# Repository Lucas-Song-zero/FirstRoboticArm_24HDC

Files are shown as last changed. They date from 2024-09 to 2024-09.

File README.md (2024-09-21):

# 总体介绍
本项目为清华大学电子工程系第27届硬件设计大赛一等奖作品——First机械手 (First Robotic Arm)

**README文档还在更新中**

#### 亮点：
1. 线驱动机械手
2. 大扭矩舵机（尽可能好的控制机械臂）
3. 设计集成度较高的压敏电阻测量模块(PCB)
4. 设计拓展版(PCB)实现更集成的功能、更美观和更高的稳定性
5. 10通道测量,更精确地测量各个关节角度
6. 使用K210实现手势识别,输出数据控制机械手
7. 使用电位计和MPU6050分别测量手肘旋转角度和小臂自转角度

#### 不足：
1. 机械手手指扭矩力道不足,精度不够高
2. 压敏电阻转换非线性,目前只能进行0-1输出
3. ESP32使用WIFI时会导致板载ADC2通道引脚失效,可以使用IO拓展增加ADC引脚
4. 设计的拓展板尺寸稍有不对,宽度大概多了1mm左右
5. K210和ESP8266的通讯很棘手,还没有完成

#### 未来可以改进的方向：
1. 显然换成电机控制会让机械臂效果好很多
2. 10自由度--5自由度机械手已经可以完成大部分日常工作
3. 压敏电阻使用反比例函数模型进行数据拟合，获得更好的效果  (大概x)

# 本Proj文件树结构:
**截止2024/9/21**
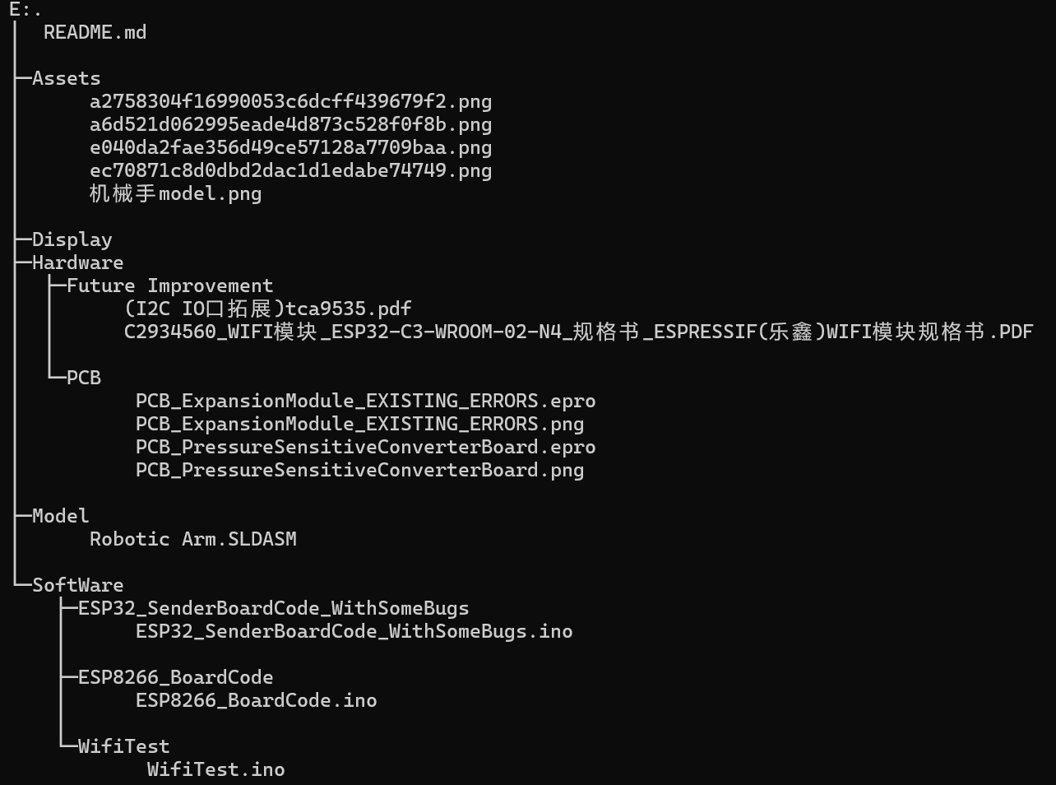
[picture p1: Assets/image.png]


# 本项目详细介绍
### 1. 机械结构+舵机安装
由whj同学进行多版机械手+机械臂结构设计以及舵机的安装。

整个过程很复杂，尤其是舵机的布线 (我们最终选择风筝线作为固定线，兼具一定的弹性和大拉力) 以及3D打印的设计需要对尺寸很强的把握。

我们总共打印了5~6版结构，最终实现了比较好的整体效果

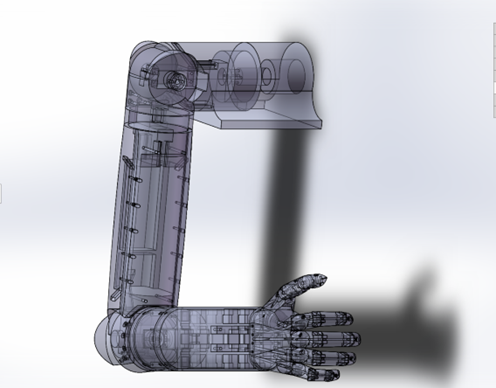
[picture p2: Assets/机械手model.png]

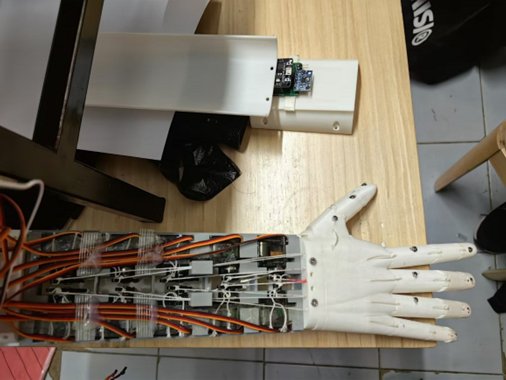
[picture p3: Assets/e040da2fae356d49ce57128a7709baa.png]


### 2. CNN
由ykp同学进行CNN架构搭建和本地跑一个轻量化CV模型，实现了基本的手势分类，准确率达到90%以上(至少显示的如此，具体使用中因为摄像范围、帧数限制等原因会降低其识别准确率)。

将这个轻量化模型部署到K210上(这里K210自带的Flash已经不足以支持这些参数的模型，所以使用了SD卡扩容)

PS: SD卡也是一个很容易出现Bug的地方（悲）
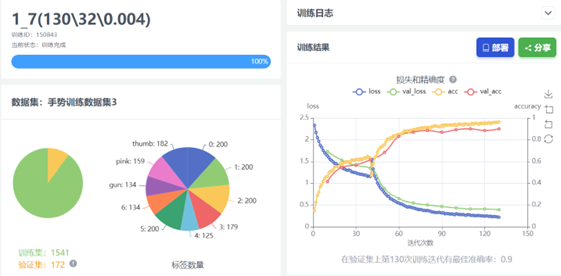
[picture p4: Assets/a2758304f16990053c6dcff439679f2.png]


### 3. 传感模块（by Lucas Song）
我创新性的使用了压敏电阻检测手指关节弯曲程度，原理很简单：将压敏电阻紧贴在手指关节处，当手指关节弯曲时，会对手指关节处的压敏电阻产生一个压力，改变其电阻阻值，从而实现从弯曲角度到电阻阻值的转化。

当然，最初方案不是这样，最初我使用的是应变片，这个不仅贵（一小片要十几块钱,我当时斥巨资买了120元的,最后一个没用上x）,变化范围极小（350±2Ω）,而且非常脆弱（根部不小心就断了）。这个"spider"方案耗费了我们1~2周时间，期间sxz同学一直在为其绘制PCB版，但是最终因为GND打孔问题导致PCB失败，整体方案替换为现在的压敏电阻。

压敏电阻变化范围非常大：KΩ~MΩ量级变化，可以说非常适合本次任务。
唯一美中不足的是使用压敏电阻可能需要数据拟合才能得到较为正确的实时角度值，但是因为时间原因以及技术复杂度，我们最终选择的是进行范围分割，只输出0、90、-1（表示无效数据）三个值只做最简单的控制。

下图是我最开始给应变片方案设计的PCB采集电路(还花了我不少钱去买运放 (生气) )

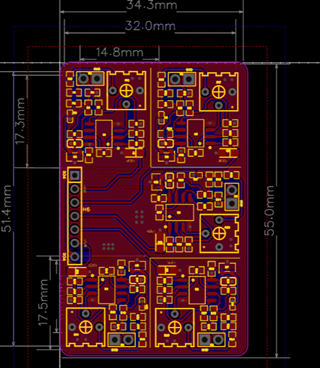
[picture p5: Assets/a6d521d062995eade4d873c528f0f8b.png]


更改方案2之后我们先是使用淘宝上买的器件做了一个小Demo(下图) ，并且用它参与了初试

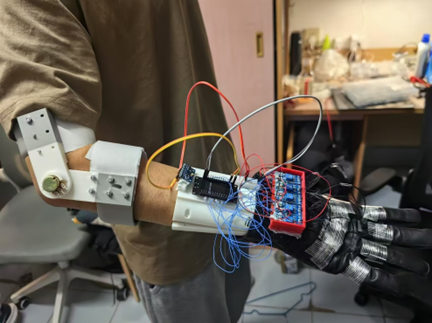
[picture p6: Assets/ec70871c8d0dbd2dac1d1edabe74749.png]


后面sxz同学的主要工作就是优化传感部分的结构：打了一个新传感模块+一个拓展板。以及优化整体的数据获取+通信模块。

**anecdote**:在决赛的前一天晚上才焊好所有板子并开始编写手指--机械手部分的控制代码，最终耗费一上午也是勉强赶上DDL了（）。这个故事告诉我们做事不要拖，不然会很破防（确信）

以及我要狠狠吐槽ESP32打开WiFi之后ADC2通道的所有引脚模拟量测量失效，1天半基本都是在怼这个问题，我开始甚至不知道，一直以为是自己的拓展板设计错了（悲）。

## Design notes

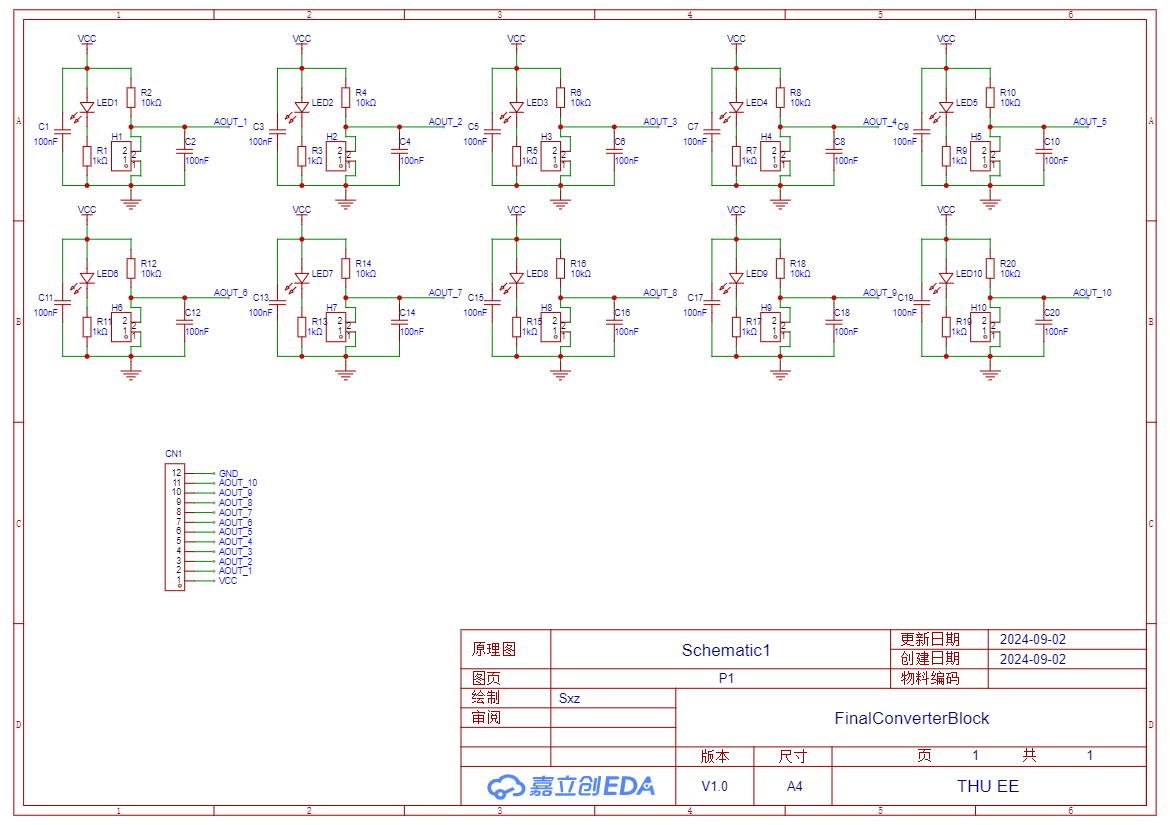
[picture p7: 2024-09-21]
Hardware/PCB/PCB_PressureSensitiveConverterBoard.png

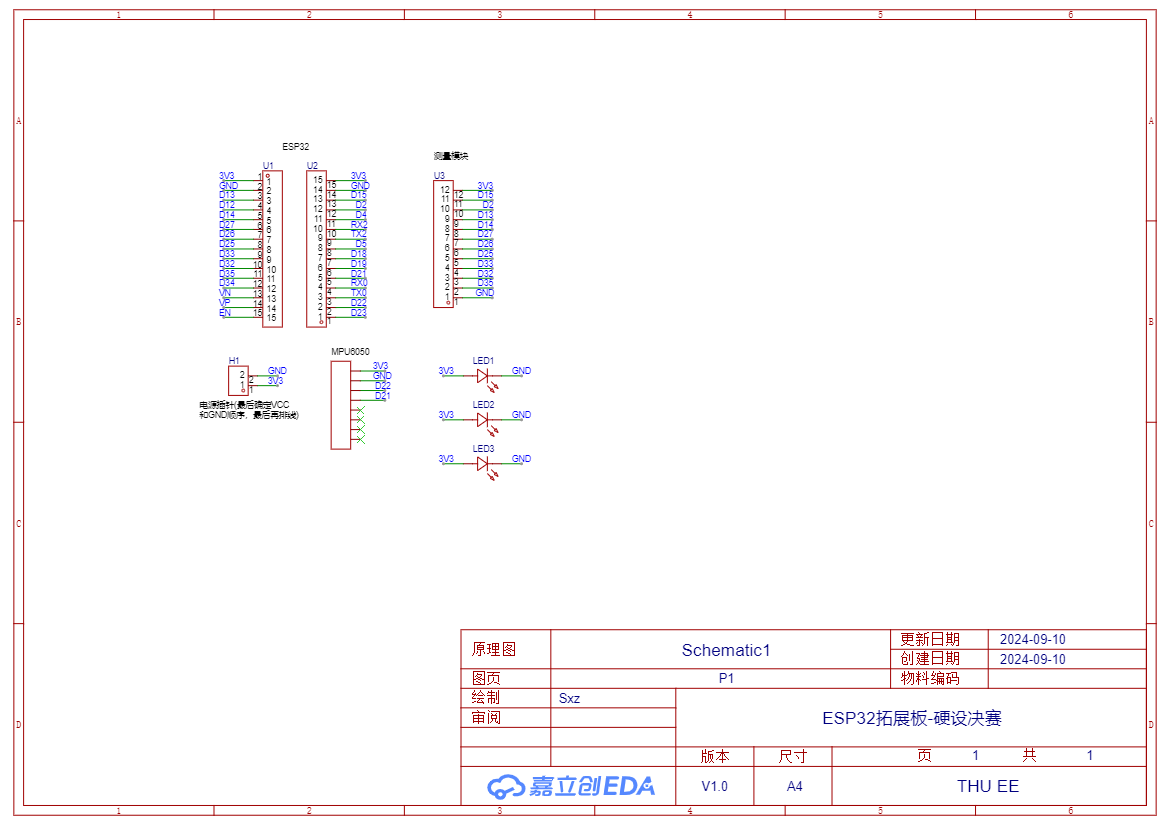
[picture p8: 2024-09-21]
Hardware/PCB/PCB_ExpansionModule_EXISTING_ERRORS.png

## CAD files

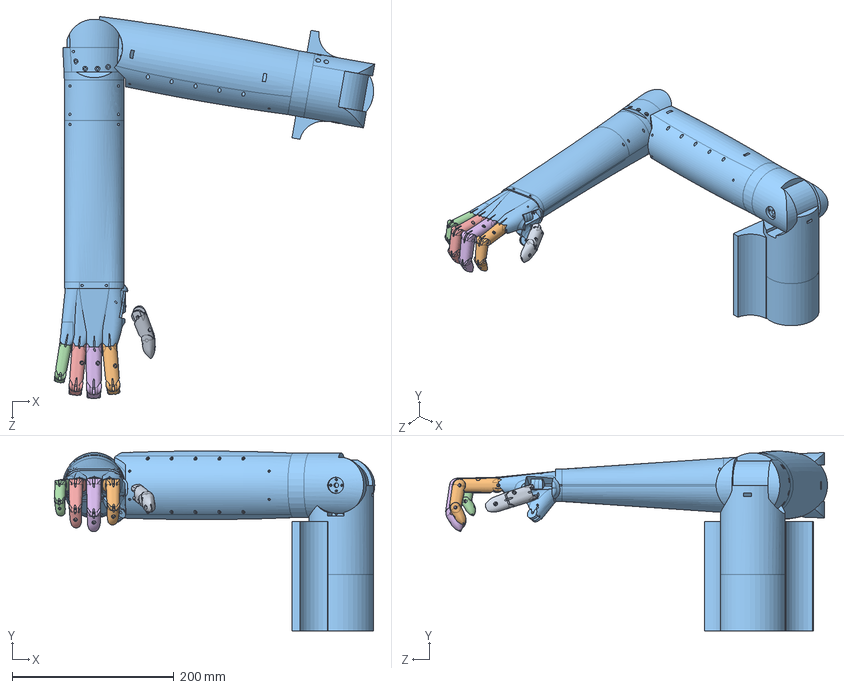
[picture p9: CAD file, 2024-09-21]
Model/Robotic Arm.SLDASM
396.2 x 222.3 x 472.1 mm
拇指1
食指2
手掌2
小指2
无名指2
中指2

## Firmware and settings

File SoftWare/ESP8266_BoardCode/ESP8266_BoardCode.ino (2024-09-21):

#include <ESP8266WiFi.h>
#include <espnow.h>
#include <Wire.h>
#include <Adafruit_PWMServoDriver.h>
Adafruit_PWMServoDriver pwm = Adafruit_PWMServoDriver(0x40);
Adafruit_PWMServoDriver pwm1 = Adafruit_PWMServoDriver(0x41);
#define Deg_0 102
#define Deg_10 114
#define Deg_20 134
#define Deg_30 155
#define Deg_40 176
#define Deg_45 187
#define Deg_50 197
#define Deg_60 218
#define Deg_70 239
#define Deg_75 249
#define Deg_80 259
#define Deg_90 280
#define Deg_100 301
#define Deg_110 321
#define Deg_120 342
#define Deg_130 363
#define Deg_140 383
#define Deg_150 398
#define Deg_160 425
#define Deg_170 446
#define Deg_180 510 
#define INT 4

static int mode = 1; // 0--跟随模式; 1--自动演示模式; 2--K210连接模式
static String comdata = ""; // 接受从K210收集到的数据
uint32_t timeCur = 0;
int fingerangles[3];
bool recData = false;

typedef struct FromESP32
{
  int FingerAngles[3]; // 10个手指关节对应的角度，从大拇指根开始0,大拇指第二个关节1,食指根2,依次到小拇指第二个关节9
} FromESP32;
FromESP32 from32;

typedef struct From8266
{
  int id;
  int shape;
} From8266;
From8266 from8266;

void OnDataRecv(uint8_t* mac_addr, uint8_t* incomingData, uint8_t len)
{
  memcpy(&from32, incomingData, sizeof(from32));
  Serial.printf("1:%d  2:%d  3:%d\n",from32.FingerAngles[0],from32.FingerAngles[1],from32.FingerAngles[2]);
  recData = true;
}

void OnDataRecv2(uint8_t* mac_addr, uint8_t* incomingData, uint8_t len)
{
  memcpy(&from8266, incomingData, sizeof(from8266));
  Serial.printf("Recv: %d\n",from8266.shape);
}

void setup() {
  // put your setup code here, to run once:
  Serial.begin(9600);
  WiFi.mode(WIFI_STA);

  // set the Interrupt Pin
  pinMode(INT, INPUT_PULLUP);
  attachInterrupt(INT, isr, FALLING); // 配置INT(4号引脚)在按下按钮(下降沿)将MODE切换

  // Init ESP-NOW
  if(esp_now_init()!= 0)
  {
    Serial.println("Error Init ESP-NOW");
    return;
  }
  // After ESP-NOW Init is Done, register for recv CB to get recv Packer Info
  // esp_now_register_recv_cb(esp_now_recv_cb_t(OnDataRecv));

  // only for test
  esp_now_set_self_role(ESP_NOW_ROLE_SLAVE);
  esp_now_register_recv_cb(OnDataRecv);
  Serial.begin(9600);
  pwm.begin();
  pwm.setPWMFreq(50);// 50HZ更新频率，相当于20ms的周期
  pwm1.begin();
  pwm1.setPWMFreq(50);// 50HZ更新频率，相当于20ms的周期
  delay(100);
}

void five()//完全张开//五
{pwm.setPWM(1, 0, Deg_50);//拇指根
pwm.setPWM(6, 0, Deg_140);//拇指中
pwm.setPWM(8, 0, Deg_130);//拇指前
pwm.setPWM(2, 0, Deg_150);//食指根
pwm.setPWM(4, 0, Deg_170);//食指中
pwm.setPWM(3, 0, Deg_10);//中指中
pwm.setPWM(0, 0, Deg_120);//中指根
pwm.setPWM(7, 0, Deg_40);//无名中
pwm.setPWM(5, 0, Deg_50);//无名根
pwm.setPWM(9, 0, Deg_0);//小指
}

void one()//一
{pwm.setPWM(1, 0, Deg_180);//拇指根
pwm.setPWM(6, 0, Deg_100);//拇指中
pwm.setPWM(8, 0, Deg_100);//拇指前
pwm.setPWM(2, 0, Deg_150);//食指根
pwm.setPWM(4, 0, Deg_170);//食指中
pwm.setPWM(3, 0, Deg_120);//中指中
pwm.setPWM(0, 0, Deg_30);//中指根
pwm.setPWM(7, 0, Deg_160);//无名中
pwm.setPWM(5, 0, Deg_130);//无名根
pwm.setPWM(9, 0, Deg_180);//小指
}

void two()//二
{pwm.setPWM(1, 0, Deg_180);//拇指根
pwm.setPWM(6, 0, Deg_100);//拇指中
pwm.setPWM(8, 0, Deg_100);//拇指前
pwm.setPWM(2, 0, Deg_150);//食指根
pwm.setPWM(4, 0, Deg_170);//食指中
pwm.setPWM(3, 0, Deg_10);//中指中
pwm.setPWM(0, 0, Deg_120);//中指根
pwm.setPWM(7, 0, Deg_160);//无名中
pwm.setPWM(5, 0, Deg_130);//无名根
pwm.setPWM(9, 0, Deg_180);//小指
}

void three()//三
{pwm.setPWM(1, 0, Deg_180);//拇指根
pwm.setPWM(6, 0, Deg_100);//拇指中
pwm.setPWM(8, 0, Deg_100);//拇指前
pwm.setPWM(2, 0, Deg_150);//食指根
pwm.setPWM(4, 0, Deg_170);//食指中
pwm.setPWM(3, 0, Deg_10);//中指中
pwm.setPWM(0, 0, Deg_120);//中指根
pwm.setPWM(7, 0, Deg_40);//无名中
pwm.setPWM(5, 0, Deg_50);//无名根
pwm.setPWM(9, 0, Deg_180);//小指
}
void four()//四
{pwm.setPWM(1, 0, Deg_180);//拇指根
pwm.setPWM(6, 0, Deg_100);//拇指中
pwm.setPWM(8, 0, Deg_100);//拇指前
pwm.setPWM(2, 0, Deg_150);//食指根
pwm.setPWM(4, 0, Deg_170);//食指中
pwm.setPWM(3, 0, Deg_10);//中指中
pwm.setPWM(0, 0, Deg_120);//中指根
pwm.setPWM(7, 0, Deg_40);//无名中
pwm.setPWM(5, 0, Deg_50);//无名根
pwm.setPWM(9, 0, Deg_0);//小指
}
void six()//六
{pwm.setPWM(1, 0, Deg_40);//拇指根
pwm.setPWM(6, 0, Deg_140);//拇指中
pwm.setPWM(8, 0, Deg_130);//拇指前
pwm.setPWM(2, 0, Deg_40);//食指根
pwm.setPWM(4, 0, Deg_70);//食指中
pwm.setPWM(3, 0, Deg_120);//中指中
pwm.setPWM(0, 0, Deg_30);//中指根
pwm.setPWM(7, 0, Deg_160);//无名中
pwm.setPWM(5, 0, Deg_130);//无名根
pwm.setPWM(9, 0, Deg_0);//小指
}
void thumb()//大拇指
{pwm.setPWM(1, 0, Deg_40);//拇指根
pwm.setPWM(6, 0, Deg_140);//拇指中
pwm.setPWM(8, 0, Deg_130);//拇指前
pwm.setPWM(2, 0, Deg_40);//食指根
pwm.setPWM(4, 0, Deg_70);//食指中
pwm.setPWM(3, 0, Deg_120);//中指中
pwm.setPWM(0, 0, Deg_30);//中指根
pwm.setPWM(7, 0, Deg_160);//无名中
pwm.setPWM(5, 0, Deg_130);//无名根
pwm.setPWM(9, 0, Deg_180);//小指
}
void fuck()//中指
{pwm.setPWM(1, 0, Deg_180);//拇指根
pwm.setPWM(6, 0, Deg_100);//拇指中
pwm.setPWM(8, 0, Deg_100);//拇指前
pwm.setPWM(2, 0, Deg_40);//食指根
pwm.setPWM(4, 0, Deg_70);//食指中
pwm.setPWM(3, 0, Deg_10);//中指中
pwm.setPWM(0, 0, Deg_120);//中指根
pwm.setPWM(7, 0, Deg_160);//无名中
pwm.setPWM(5, 0, Deg_130);//无名根
pwm.setPWM(9, 0, Deg_180);//小指
}

void SETPWM(Adafruit_PWMServoDriver pwm,int port,int initdeg,int finaldeg)//调整手臂关节
{int i=0;
if(initdeg>finaldeg)
{
  for(i=initdeg;i>finaldeg;i--)
  {
    pwm.setPWM(port,0,i);
    delay(5);
  }
}
else
{
  for(i=initdeg;i<finaldeg;i++)
  {
    pwm.setPWM(port,0,i);
    delay(5);
  }
}

}
IRAM_ATTR void isr()
{
  mode = (mode+1)%3;
}

void Follow()
{
  
  // from32是通过wifi获得的数据,内存的数据格式详情参见前面的定义
  int angles[3];
  if(recData) // 接受到数据,可以更新一次角度值
  {
    for(int i=0;i<3;++i)
    {
      angles[i]=from32.FingerAngles[i];
    }
    // 下面是角度控制
    if(angles[0]==90)
    {
      pwm.setPWM(2, 0, Deg_40);//食指根
      pwm.setPWM(4, 0, Deg_70);//食指中
    }
    else 
    {
      pwm.setPWM(2, 0, Deg_130);//食指根
      pwm.setPWM(4, 0, Deg_170);//食指中
    }
    if(angles[1]==90)
    {
      pwm.setPWM(0, 0, Deg_30);//中指根
      pwm.setPWM(3, 0, Deg_120);//中指中
    }
    else 
    {
      pwm.setPWM(0, 0, Deg_120);//中指根
      pwm.setPWM(3, 0, Deg_10);//中指中
    }
    if(angles[2]==90)
    {
      pwm.setPWM(1, 0, Deg_180);//拇指根
      pwm.setPWM(7, 0, Deg_160);//无名中
      pwm.setPWM(5, 0, Deg_130);//无名根
      pwm.setPWM(9, 0, Deg_180);//小指
    }
    else 
    {
      pwm.setPWM(1, 0, Deg_40);//拇指根
      pwm.setPWM(7, 0, Deg_40);//无名中
      pwm.setPWM(5, 0, Deg_50);//无名根
      pwm.setPWM(9, 0, Deg_0);//小指
    }

    // 下面是把recData设为false，等待下一次接受数据
    recData=false;
  }
  
 
  delay(1000);

}

void AutoDisplay()
{
  // 自动展示一些动作
  
  SETPWM(pwm1,1,Deg_70,Deg_10);
  pwm1.setPWM(8,0,Deg_0);
  delay(1500);
  // thumb();
  // delay(2000);
  one();
  delay(2000);
  two();
  delay(2000);
  three();
  delay(2000);
  four();
  delay(2000);
  five();
  delay(2000);
  six();
  delay(2000);
  five();
  SETPWM(pwm1,1,Deg_10,Deg_70);
  pwm1.setPWM(8,0,Deg_90);
  delay(2000);

}

void K210Link()
{
  // 和K210连接,接受信号
  while(1)
  {
    Serial.printf("Shape:%d",from8266.shape);

    switch(from8266.shape)
    {
      case 0:
      {
        fuck();
        break;
      }

      case 1:
      {
        five();
        delay(3000);
        one();
        break;
      }

      case 2:
      {
        two();
        break;
      }

      case 3:
      {
        four();
        delay(500);
        three();
        break;
      }

      case 4:
      {
        four();
        break;
      }

      case 5:
      {
        five();
        break;
      }

      case 6:
      {
        six();
        break;
      }

      case 7: // thumb
      {
        thumb();
        break;
      }

      case 8: // gun
      {
        break;
      }

      case 9: // pink
      {
        break;
      }
    }
  delay(3000);
  }
}

void loop() {
  // put your main code here, to run repeatedly:
    mode=0;

  switch(mode)
  {
    case 0:
    {
      esp_now_register_recv_cb(OnDataRecv);
      Follow();
      break;
    }

    case 1:
    {
      AutoDisplay();
      break;
    }

    case 2:
    {
      esp_now_register_recv_cb(OnDataRecv2);
      pwm1.setPWM(1,0,Deg_10);
      pwm1.setPWM(8,0,Deg_0);
      five();
      delay(3000);
      K210Link();
      break;
    }
    default:
    {
      Serial.println("Wrong Mode!");
    }
  }
}

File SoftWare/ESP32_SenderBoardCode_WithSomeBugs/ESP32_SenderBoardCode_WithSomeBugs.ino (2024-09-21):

#include <esp_now.h>
#include <WiFi.h>
#include <SimpleKalmanFilter.h>

#define Sensor1 33
#define Sensor2 32
#define Sensor3 35

uint8_t RecAddr[] = {0xA8,0x48,0xFA,0xDC,0xCF,0x13}; // receiver's MAC address

esp_now_peer_info_t peerInfo;

typedef struct SendFrom32
{
  int FingerAngles[3];
} SendFrom32;
SendFrom32 dataFrom32;  // data to be sent

void setup()
{
  Serial.begin(9600);
  // pinMode(27,INPUT);
  // pinMode(26,INPUT);
  // pinMode(25,INPUT);
  // pinMode(33,INPUT);
  // pinMode(32,INPUT);
  // pinMode(35,INPUT);
  // pinMode()
  pinMode(Sensor1, INPUT);
  pinMode(Sensor2, INPUT);
  pinMode(Sensor3, INPUT);

  WiFi.mode(WIFI_STA);
  if(esp_now_init() != ESP_OK)
  {
    Serial.println("Error Init EPSNOW");
    return;
  }
  // esp_now_register_send_cb(OnDataSent);

  memcpy(peerInfo.peer_addr, RecAddr, sizeof(RecAddr));
  peerInfo.channel = 0;
  peerInfo.encrypt = false;

  if(esp_now_add_peer(&peerInfo) != ESP_OK)
  {
    Serial.println("failed to add peer");
    return;
  }
}

void OnDataSent(const uint8_t* mac_addr, esp_now_send_status_t status)
{

}


int transform(int index,uint16_t v)
{
  switch(index)
  {
    case 1:
      return (v >= 2500) ? 0 : ((v <= 1800) ? 90 : -1); // -1 表示无效值
      break;

    case 3:
      return (v >= 3000) ? 0 : ((v <= 1500) ? 90 : -1); // -1 表示无效值
      break;
  
    case 5:
      return (v >= 3800) ? 0 : ((v <= 2500) ? 90 : -1); // -1 表示无效值
      break;
  }
  return -1; // 对于无效的索引返回-1
}

void loop()
{
  Serial.printf("1:%d\n",analogRead(33));
  Serial.printf("3:%d\n",analogRead(32));
  Serial.printf("5:%d\n",analogRead(35));

  delay(100);

  dataFrom32.FingerAngles[0] = transform(1, analogRead(33));
  dataFrom32.FingerAngles[1] = transform(3, analogRead(32));
  dataFrom32.FingerAngles[2] = transform(5, analogRead(35));

  delay(150);
  
  for(int i=0;i<3;++i)
  {
    Serial.printf("FingerAnlges[%d]:%d\n",i,dataFrom32.FingerAngles[i]);
  }
  
  esp_err_t res = esp_now_send(RecAddr, (uint8_t*)&dataFrom32, sizeof(dataFrom32));
  delay(100);
}

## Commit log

2024-09-21 First Commit As Init_2024/9/21
    [Robotic Arm.SLDASM]
2024-09-21 Update README.md: Correct Photo Display Format
    更改了README中的图片地址格式，正确显示了图片
